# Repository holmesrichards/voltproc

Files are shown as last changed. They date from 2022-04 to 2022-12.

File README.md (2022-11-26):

# Voltage processor

This is a voltage processor module based on designs by ARP and MFOS.

There are two sum sections: One has four inputs, two with attenuators (normaled to -10 V and +10 V) and two with fixed unity gain; the other has two inputs, one with attenuator (normaled to +10 V) and one with fixed unity gain. Each sum has two outputs, normal and inverted.

There also is a lag processor section. Switches allow selection of slow or fast ranges and RC or linear ramping, and a knob adjusts the lag time.

The sum sections are derived from the ARP 2600 schematics. Differences:

* Obviously, this is a module, so there is no normal connection to keyboard CV; instead the second input of the first sum is normaled to +10 V.
* Added second inverting stages for normal plus inverted outputs.
* TL07x op amps in place of LM301.
* Added series output resistors.

The lag processor is based on a section of the MFOS Multi Function Module. Differences:

* Common input and output for both linear and RC circuits.
* Shorter minimum linear lag time.
* 1k series resistors on outputs.

## Current draw
20 mA +12 V, 20 mA -12 V

## Photos

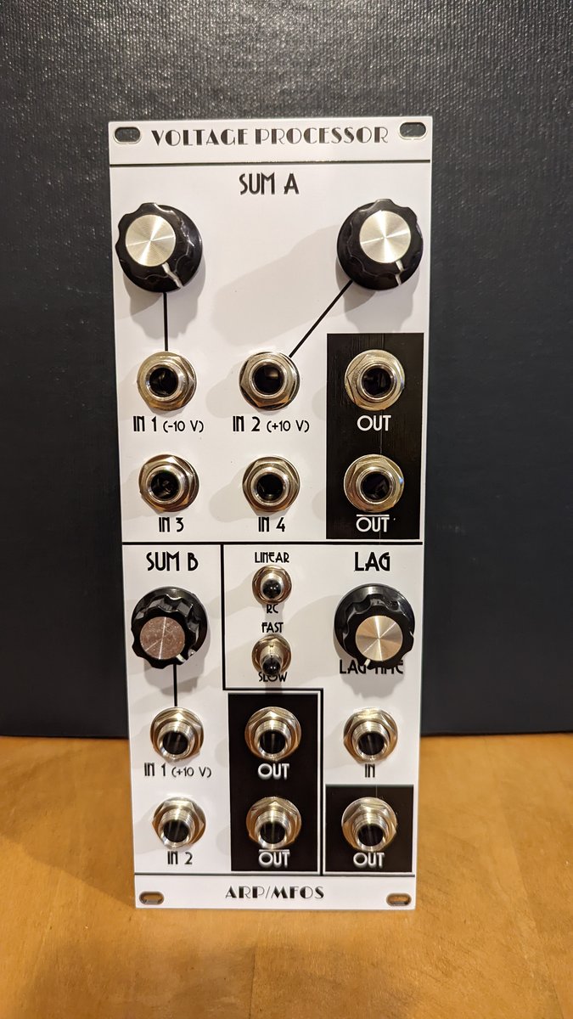
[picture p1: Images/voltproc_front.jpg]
voltproc_front


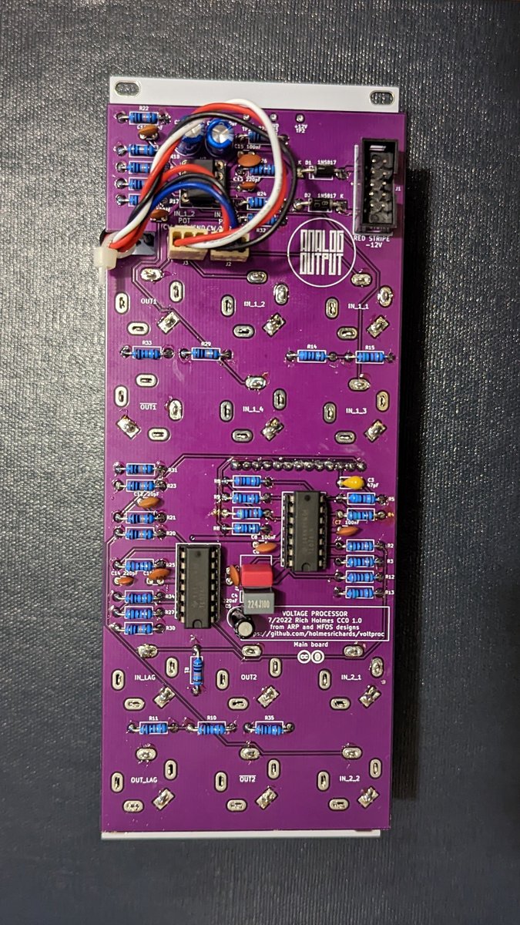
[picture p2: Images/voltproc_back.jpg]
voltproc_front


## Documentation

* [Schematic](Docs/voltproc.pdf)
* PCB layout: [front](Docs/voltproc_layout_front.pdf), [back](Docs/voltproc_layout_back.pdf)
* [BOM](Docs/voltproc_bom.md)
* [Build notes](Docs/build.md)
* [Blog post](https://analogoutputblog.wordpress.com/2022/11/26/processing-voltages/)

## GitHub repository

* [https://github.com/holmesrichards/voltproc](https://github.com/holmesrichards/voltproc)

## Submodules

## Submodules

This repo uses submodules aoKicad and Kosmo_panel, which provide needed libaries for KiCad. To clone:

```
git clone git@github.com:holmesrichards/voltproc.git
git submodule init
git submodule update
```

Alternatively do

```
git clone --recurse-submodules git@github.com:holmesrichards/voltproc.git
```

Or if you download the repository as a zip file, you must also click on the "aoKicad" and "Kosmo\_panel" links on the GitHub page (they'll have "@ something" after them) and download them as separate zip files which you can unzip into this repo's aoKicad and Kosmo\_panel directories.

If desired, copy the files from aoKicad and Kosmo\_panel to wherever you prefer (your KiCad user library directory, for instance, if you have one). Then in KiCad, go into Edit Symbols and add symbol libraries 

```
aoKicad/ao_symbols
Kosmo_panel/Kosmo
```
and go into Edit Footprints and add footprint libraries 
```
aoKicad/ao_tht
Kosmo_panel/Kosmo_panel.
```

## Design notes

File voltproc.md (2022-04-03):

# Voltage processor

This is a utility synth module in Kosmo format. It started as an adaptation of the voltage processor section from the ARP 2600, but with some modifications, and it ended up with the ARP lag processor replaced by one based on that of the Music From Outer Space [Multi Function Module](http://musicfromouterspace.com/analogsynth_new/MULTIFUNCTIONMODULE/MULTIFUNCTIONMODULE.php).

There are three independent sections: Two CV summers and a lag processor.

The summers can be used to add DC offsets to control voltages and to invert them as well as summing them. The first summer has four inputs. Two have attenuators, and these inputs are normalled to -10 V and +10 V. The sum of all four inputs, both inverted and non inverted, goes to output jacks. The second summer is the same but has only two inputs, one with an attenuator and normalled to +10 V.

The lag processor can be used for portamento and glide effects, or as a simple AR envelope generator or a manually controlled low pass filter to smooth rapid changes in a control voltage. The speed is controlled by a knob, and by a switch that selects slow or fast speed ranges. Another switch selects between linear ramping and RC shape lag.

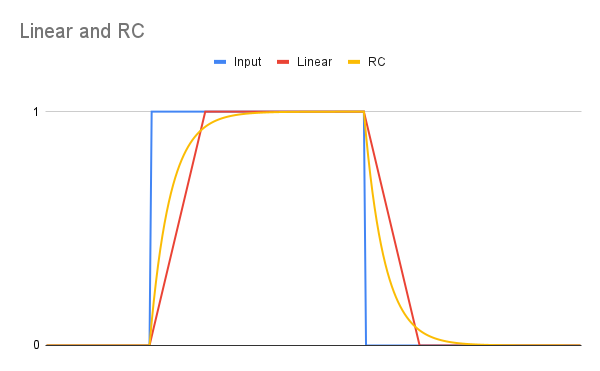
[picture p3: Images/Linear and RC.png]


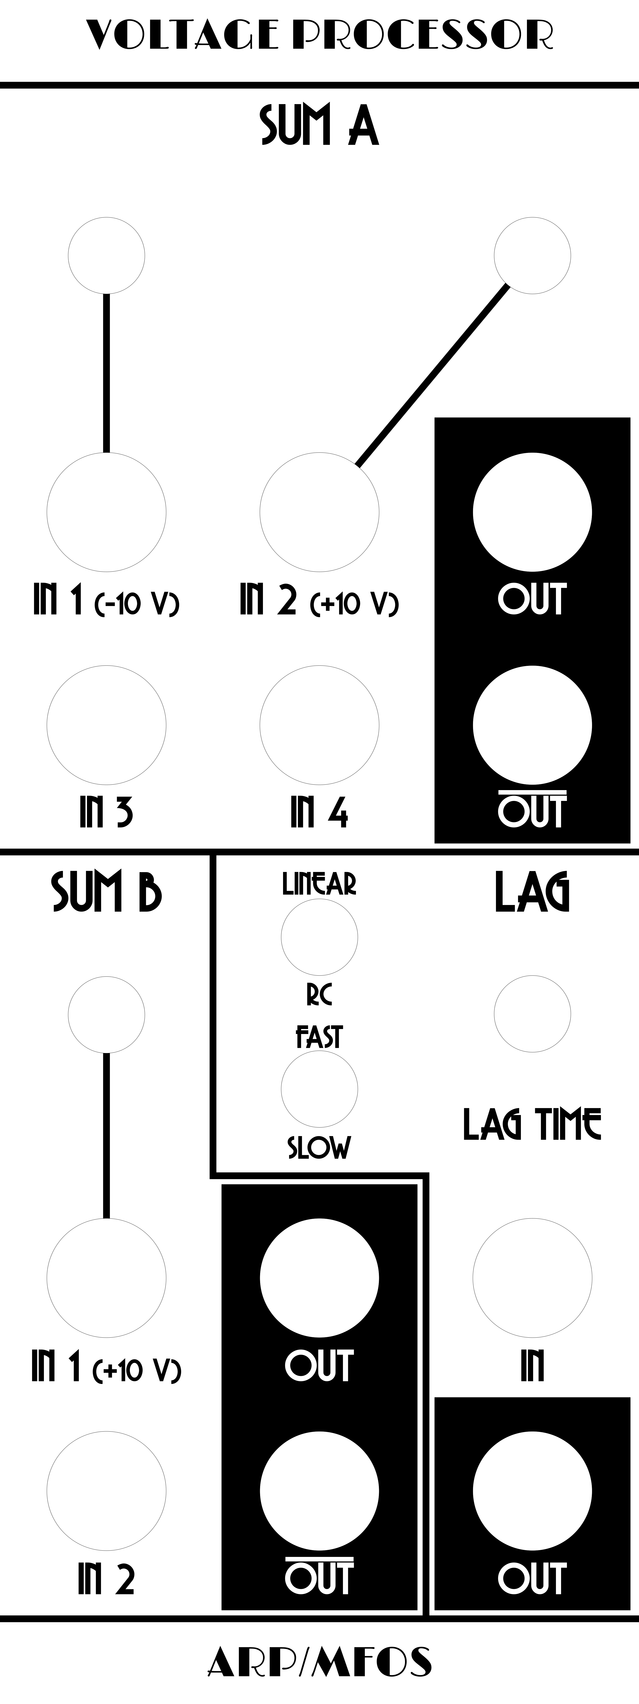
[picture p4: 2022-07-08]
Images/voltproc_panel_art.png

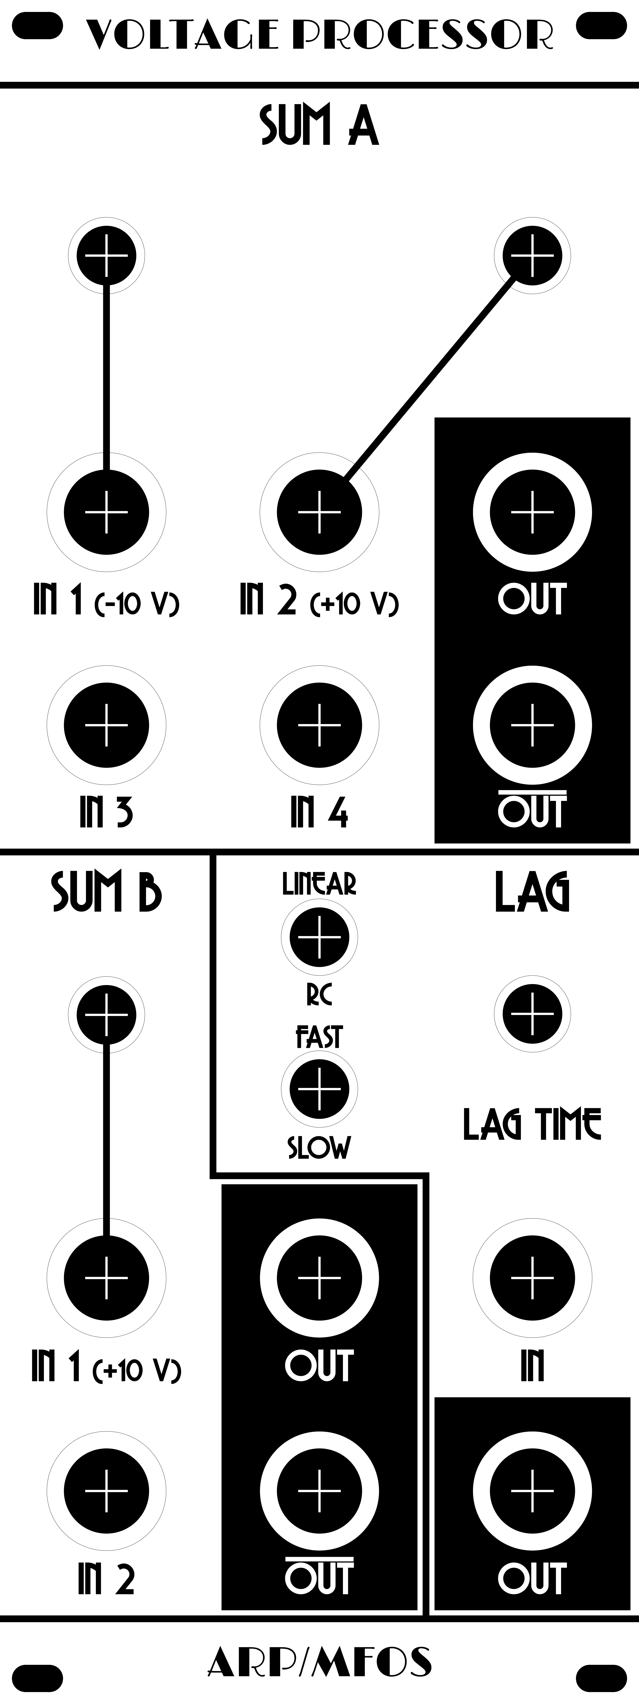
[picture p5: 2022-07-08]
Images/voltproc_panel_holes.png

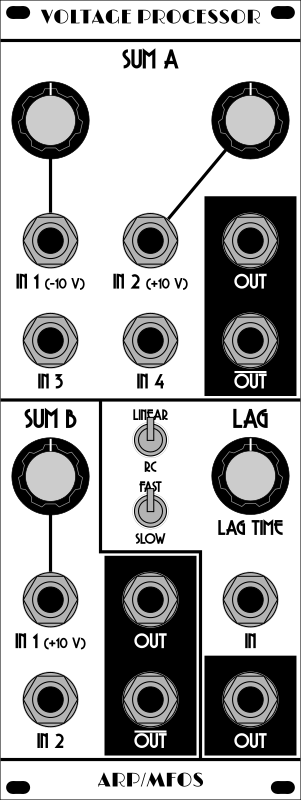
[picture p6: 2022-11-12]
Images/voltproc_panel.png

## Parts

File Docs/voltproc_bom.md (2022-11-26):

# Voltage processor BOM

Sat 26 Nov 2022 12:45:53 PM EST

Generated from schematic by Eeschema 6.0.9-8da3e8f707~117~ubuntu22.04.1

**Component Count:** 81

| Refs | Qty | Component | Description | Vendor | SKU |
| ----- | --- | ---- | --- | ---- | ---- |
| C1, C2 | 2 | 10uF | Electrolytic capacitor, 2.5 mm pitch | Tayda | A-4349 |
| C3 | 1 | 47pF | Ceramic capacitor, 5 mm pitch |  |  |
| C4 | 1 | 220nF | Film capacitor, 5 mm pitch | Tayda | A-984 |
| C5 | 1 | 2.2uF | Non polarized electrolytic capacitor, 2.5 mm pitch | Tayda | A-4223 |
| C6 | 1 | 1uF | Film capacitor, 5 mm pitch | Tayda | A-4755 |
| C7, C8, C9, C10, C15, C16 | 6 | 100nF | Ceramic capacitor, 2.5 mm pitch | Tayda | A-553 |
| C11, C12 | 2 | 20pF | Ceramic capacitor, 2.5 mm pitch |  |  |
| C13, C14 | 2 | 220pF | Ceramic capacitor, 2.5 mm pitch |  |  |
| D1, D2 | 2 | 1N5817 | Schottky Barrier Rectifier Diode, DO-41 | Tayda | A-159 |
| J1 | 1 | Synth_power_2x5 | Shrouded pin header 2.54 mm pitch 2x5 | Tayda | A-2939 |
| J2, J3 | 2 | 3_pin_Molex_header | KK254 Molex header, 3 position | Tayda | A-805 |
| J4 | 1 | Conn_01x13 | Pin header 2.54 mm pitch 1x13 |  |  |
| J5, J6 | 2 | 3_pin_Molex_connector | KK254 Molex connector, 3 position | Tayda | A-827 |
| J7 | 1 | Conn_01x13 | Pin socket 2.54 mm pitch 1x13 |  |  |
| J8, J9, J10, J11, J12, J13, J14, J15, J16, J17, J18, J19 | 12 | Jack | 1/4" audio jack, switched |Tayda  | A-1121 |
| R1, R10, R16, R17, R18, R19, R20, R21, R22, R23, R28, R29, R30, R31 | 14 | 100k | Resistor |  |  |
| R2, R3, R9, R24, R25, R26, R27 | 7 | 10k | Resistor |  |  |
| R4 | 1 | 10M | Resistor |  |  |
| R5 | 1 | 68k | Resistor |  |  |
| R6 | 1 | 20k | Resistor |  |  |
| R7 | 1 | 47k | Resistor |  |  |
| R8 | 1 | 200R | Resistor |  |  |
| R11, R32, R33, R34, R35 | 5 | 1k | Resistor |  |  |
| R12, R14 | 2 | 2.7k | Resistor |  |  |
| R13, R15 | 2 | 15k | Resistor |  |  |
| RV1, RV2 | 2 | B100k | Panel mount potentiometer | Tayda | A-5606 or A-1984 |
| RV3 | 1 | B100k | Board mount vertical 16mm potentiometer | Tayda | A-1628 |
| RV4 | 1 | B1M | Board mount vertical dual gang 16mm potentiometer | Tayda | A-1294 |
| SW1, SW2 | 2 | SW_DPDT_x2 | DPDT miniature toggle switch | Tayda | A-3188 |
| U1, U2 | 2 | TL074 | Quad op amp, DIP-14 | Tayda | A-1138 |
| U3 | 1 | TL072 | Dual op amp, DIP-8 | Tayda | A-037 |
| | 2 | | 14 pin DIP socket | Tayda | A-004 |
| | 1 | | 8 pin DIP socket | Tayda | A-001 |
| | 4 | | knob | | |

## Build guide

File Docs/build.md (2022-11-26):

# Voltage processor build notes

This is a straightforward build. Since there are many panel components be sure to mount the panel on them before soldering them in place. Follow markings on PCB to connect the Molex connectors in correct order to the pots.

**Errata:** In the first run PCB, R7 is marked 4.7k. This is the value used in the MFOS design but I feel it gives too slow a minimum linear ramp. I recommend changing it to 47k. This value has been updated in the design files.

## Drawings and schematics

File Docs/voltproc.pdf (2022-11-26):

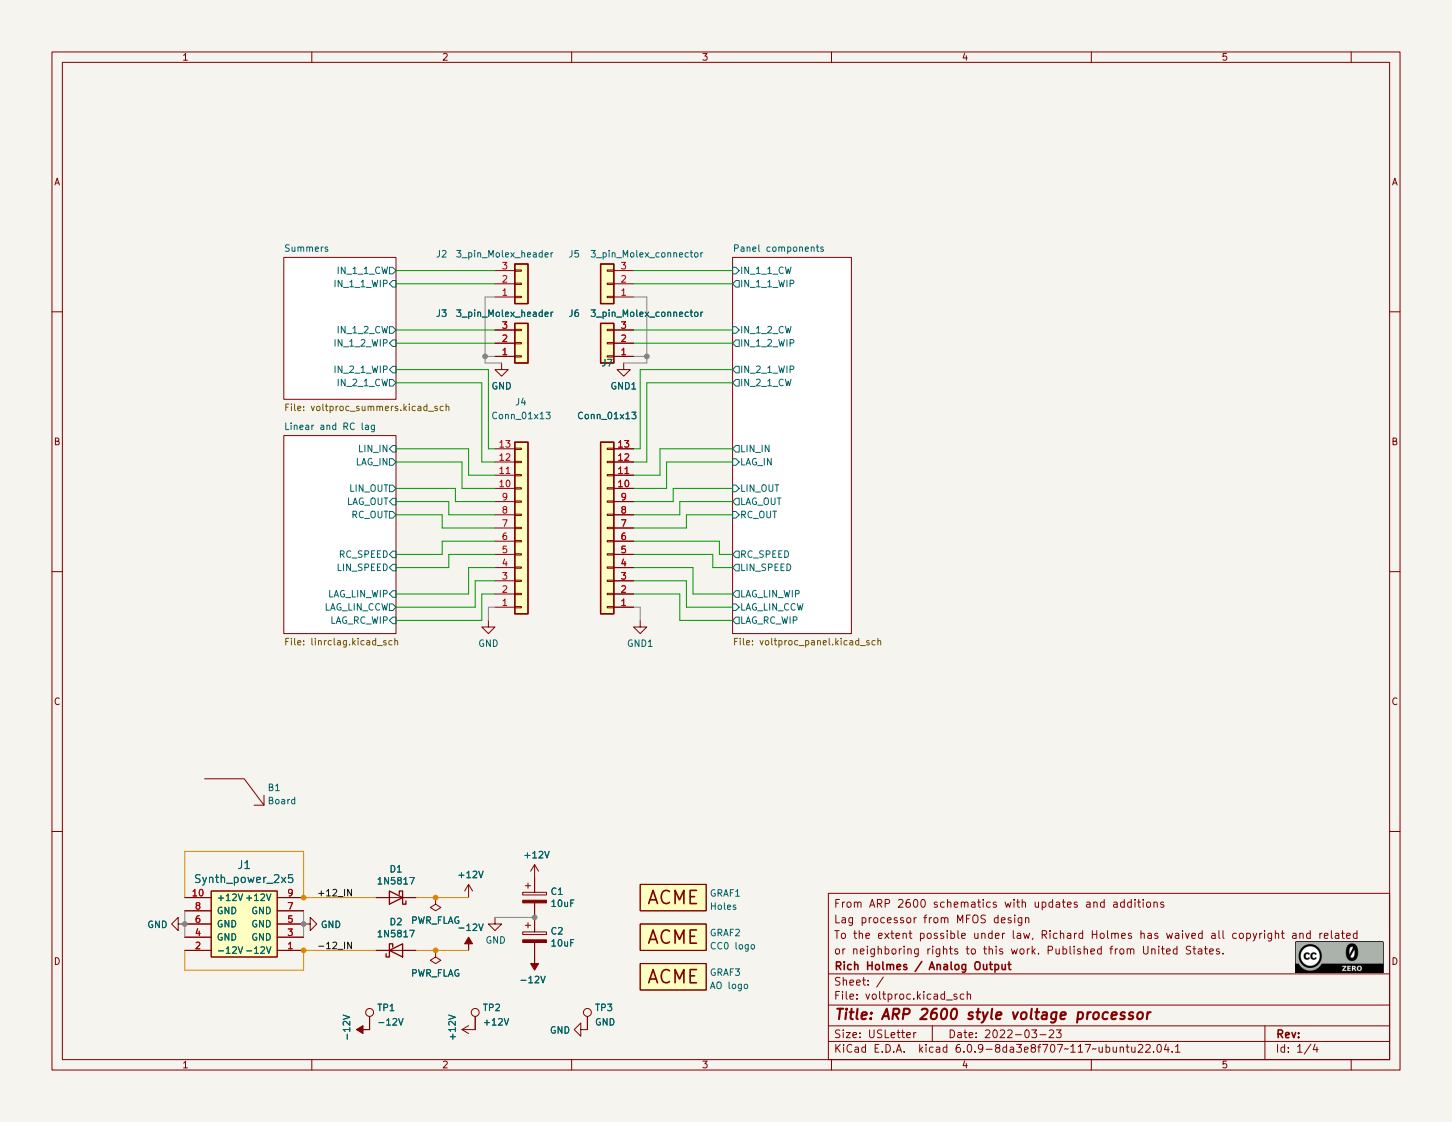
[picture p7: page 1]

Linear and RC lag

From ARP 2600 schematics with updates and additions
Lag processor from MFOS design
To the extent possible under law, Richard Holmes has waived all copyright and related
or neighboring rights to this work. Published from United States.
File: voltproc.kicad_sch Sheet: / Rich Holmes / Analog Output

Id: 1/4 Title: ARP 2600 style voltage processor

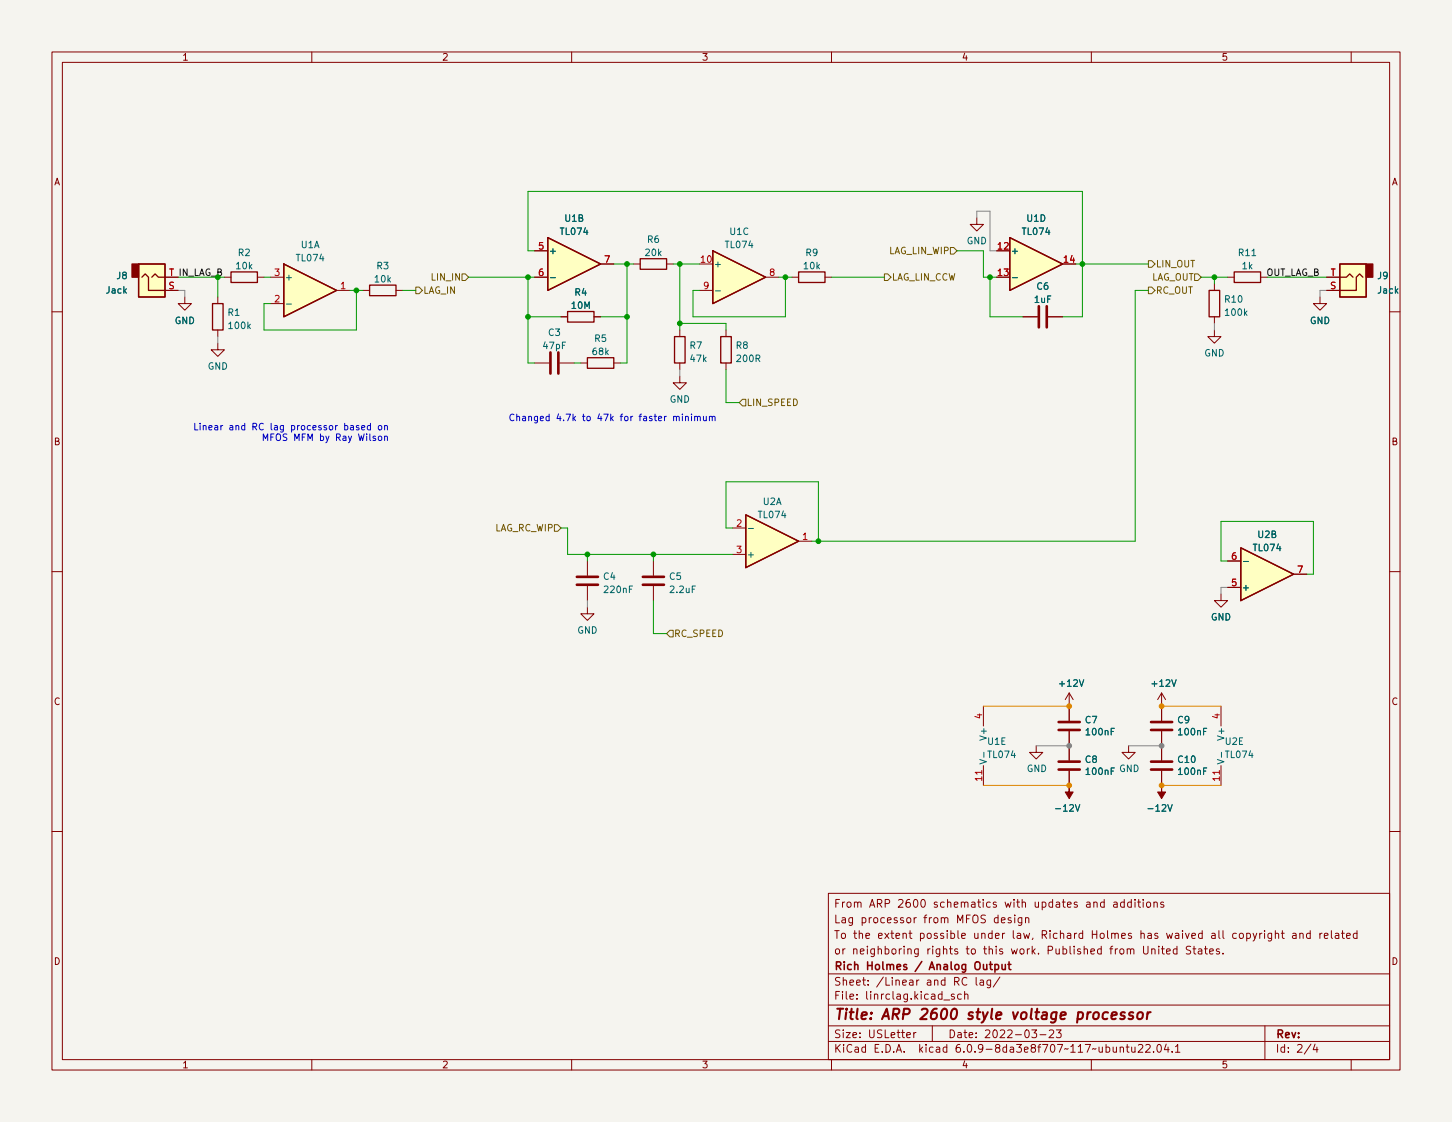
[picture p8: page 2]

Linear and RC lag processor based on

From ARP 2600 schematics with updates and additions
Lag processor from MFOS design
To the extent possible under law, Richard Holmes has waived all copyright and related
or neighboring rights to this work. Published from United States.
Rich Holmes / Analog Output
Sheet: /Linear and RC lag/
File: linrclag.kicad_sch
Id: 2/4 Title: ARP 2600 style voltage processor

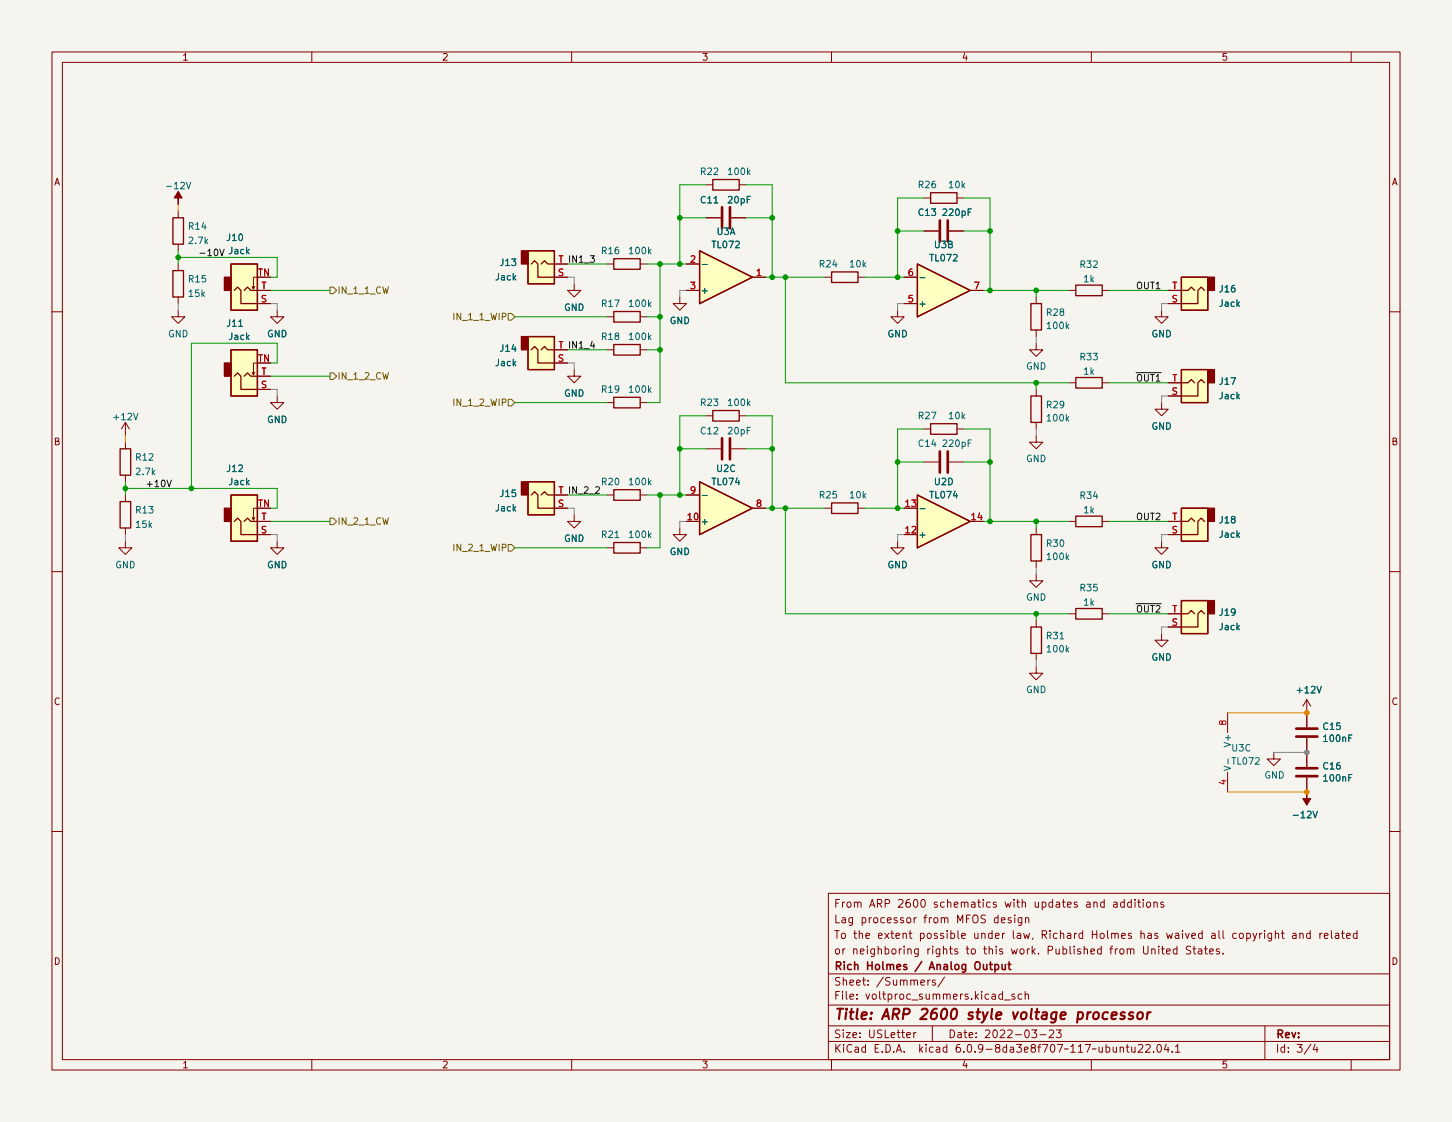
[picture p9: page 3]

From ARP 2600 schematics with updates and additions
Lag processor from MFOS design
To the extent possible under law, Richard Holmes has waived all copyright and related
or neighboring rights to this work. Published from United States.
File: voltproc_summers.kicad_sch Sheet: /Summers/ Rich Holmes / Analog Output

Id: 3/4 Title: ARP 2600 style voltage processor

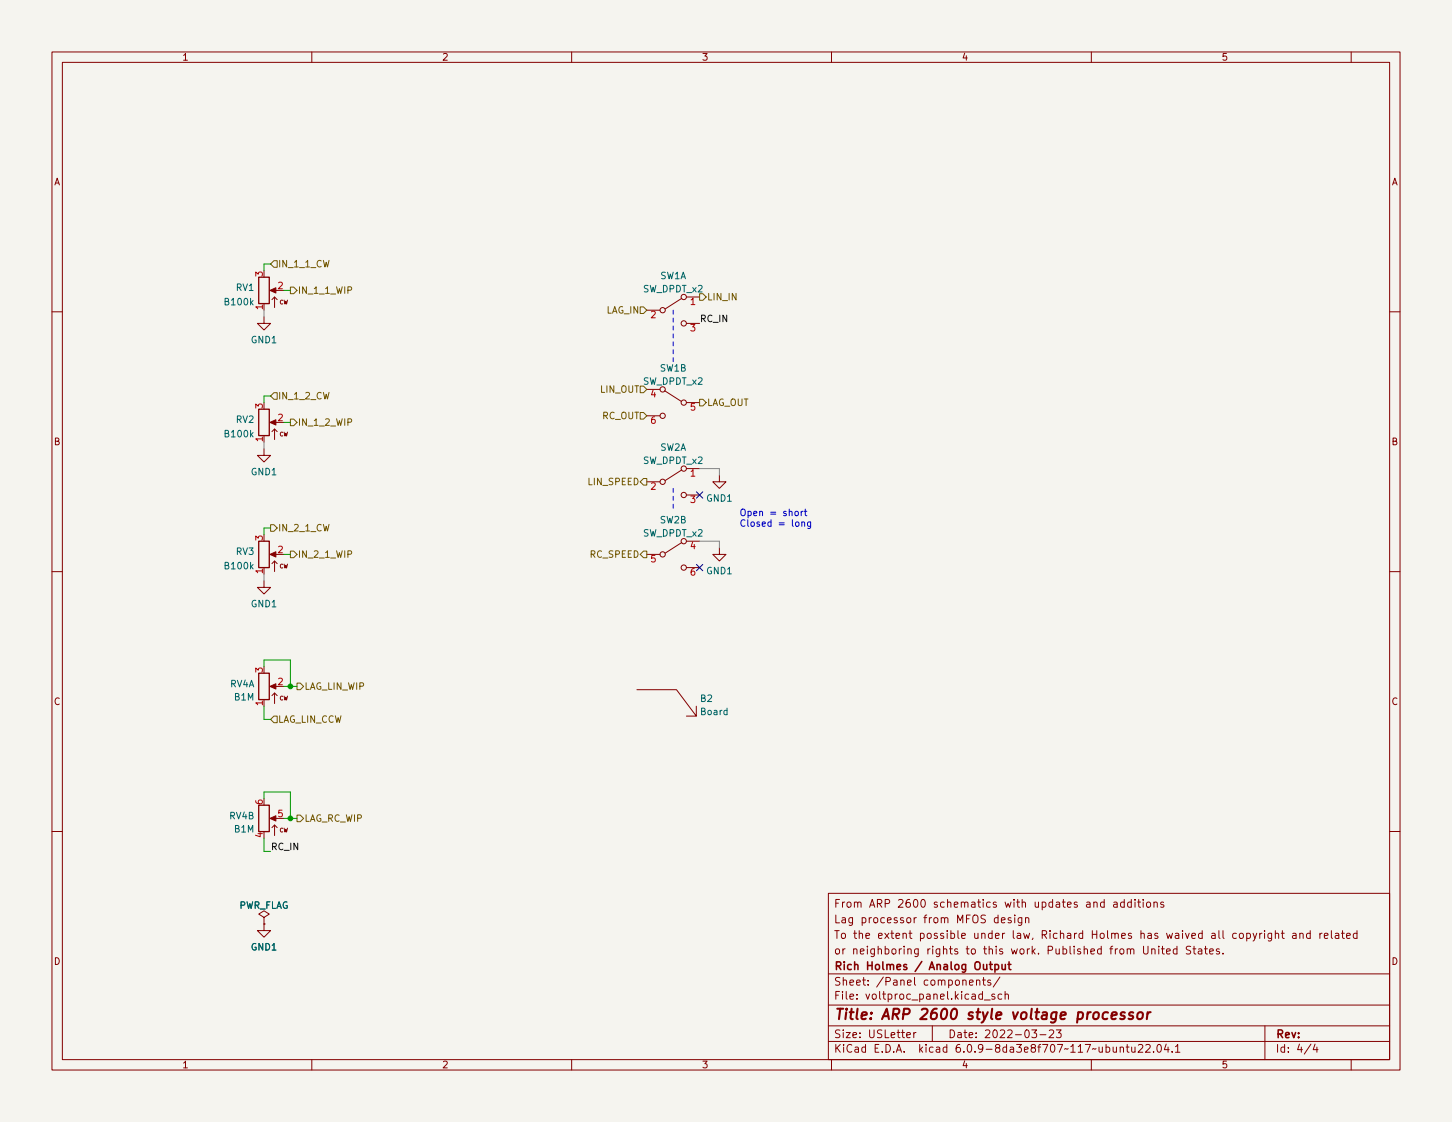
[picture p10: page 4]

From ARP 2600 schematics with updates and additions
Lag processor from MFOS design
To the extent possible under law, Richard Holmes has waived all copyright and related
or neighboring rights to this work. Published from United States.
Rich Holmes / Analog Output
Sheet: /Panel components/
File: voltproc_panel.kicad_sch
Id: 4/4 Title: ARP 2600 style voltage processor

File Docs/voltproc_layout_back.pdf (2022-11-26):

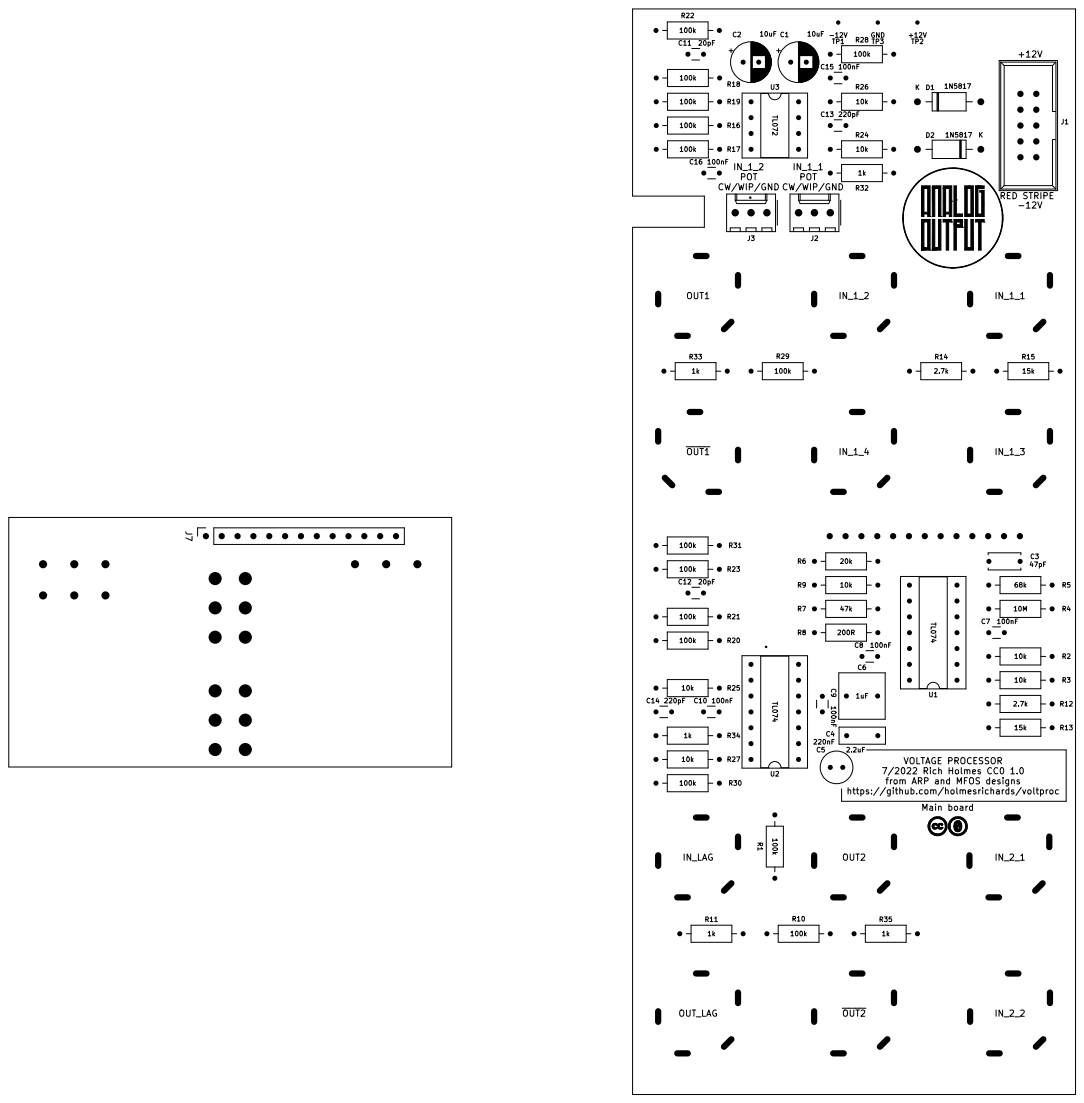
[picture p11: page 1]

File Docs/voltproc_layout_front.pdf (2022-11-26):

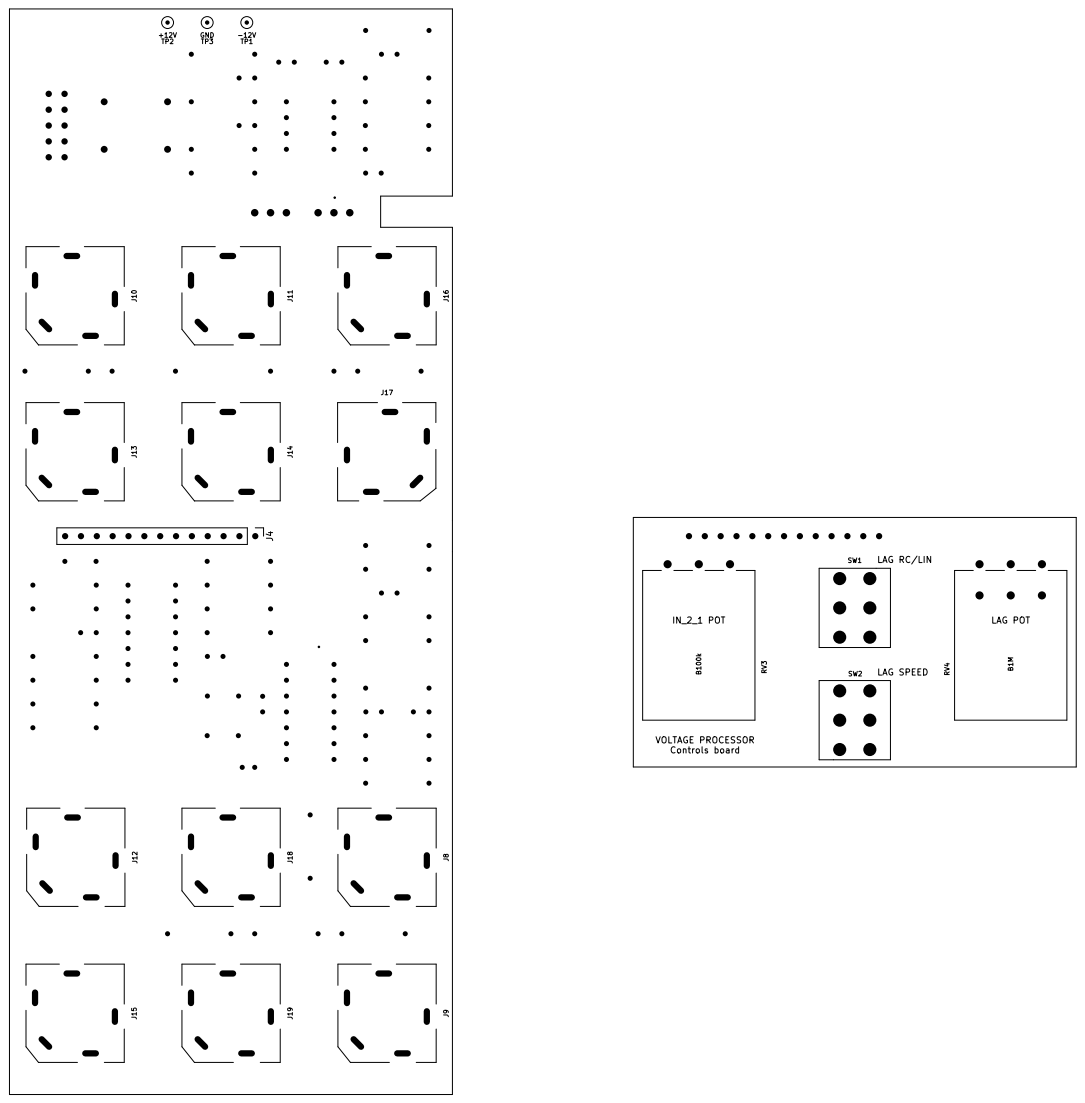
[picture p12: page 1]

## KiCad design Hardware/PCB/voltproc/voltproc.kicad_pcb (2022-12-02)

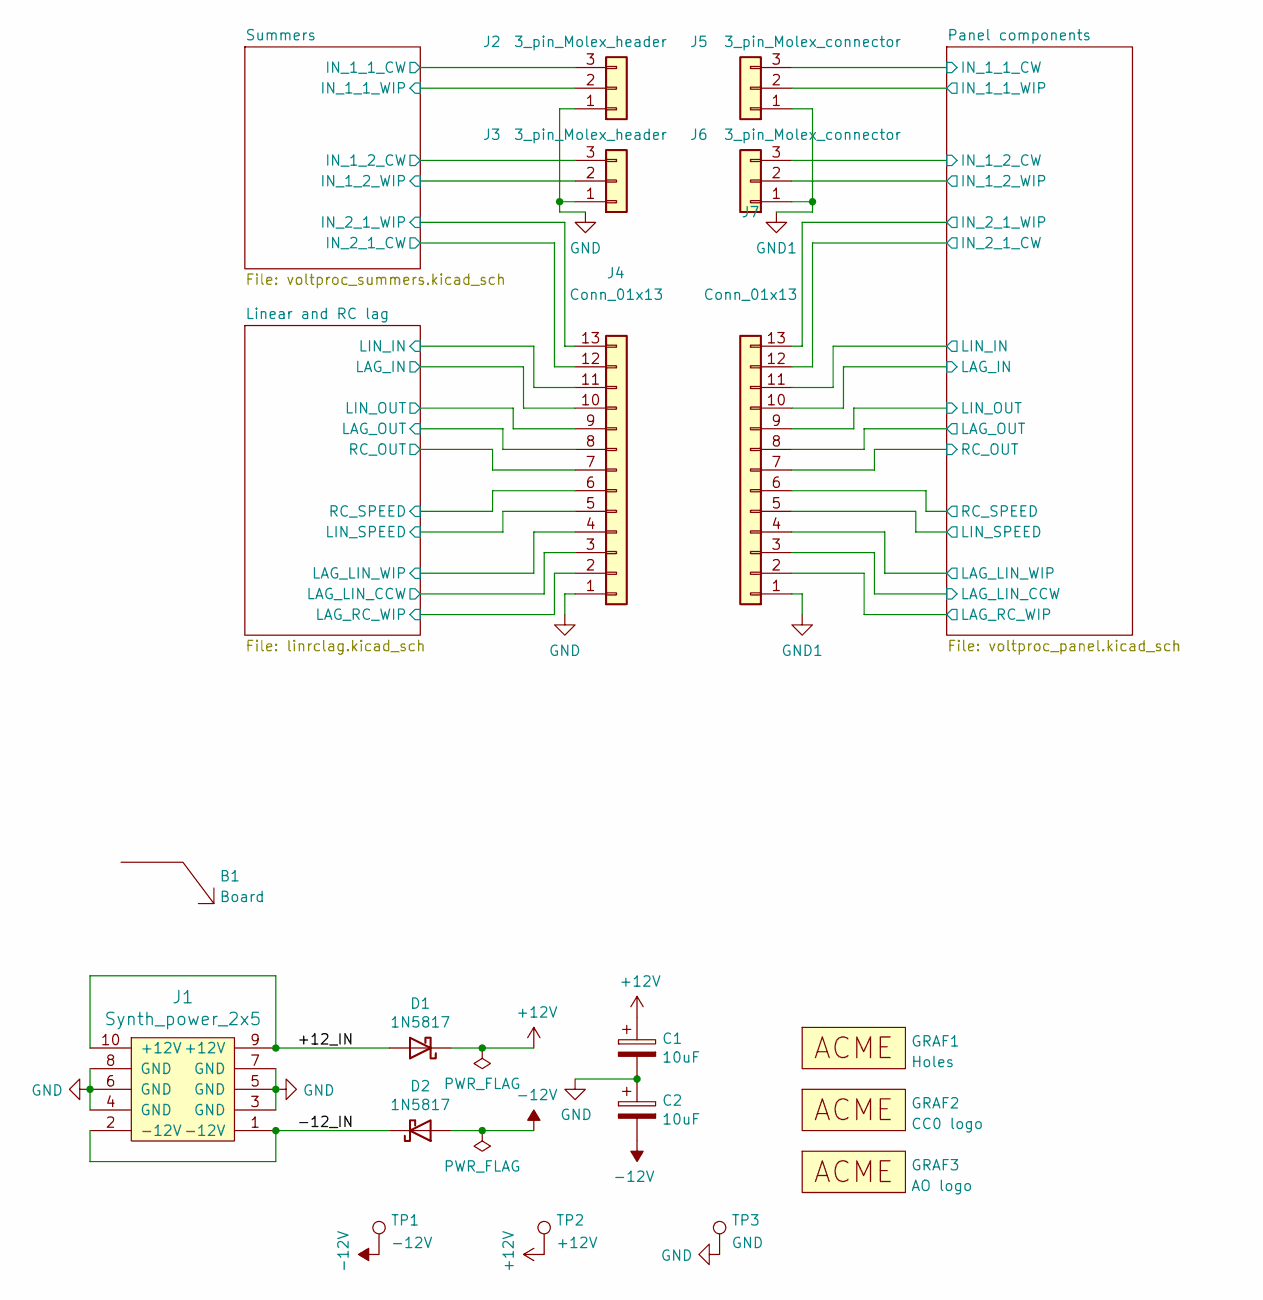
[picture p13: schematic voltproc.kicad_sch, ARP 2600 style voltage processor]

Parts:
B1: Board; Board_Marker
C1, C2: 10uF; CP_Radial_D6.3mm_P2.50mm
D1, D2: 1N5817; D_DO-41_SOD81_P10.16mm_Horizontal
GRAF1: Holes; voltproc_panel_holes
GRAF2: CC0 logo; CC0_logo
GRAF3: AO logo; analogoutput
J1: Synth_power_2x5; Power_Header
J2, J3: 3_pin_Molex_header; Molex_KK-254_AE-6410-03A_1x03_P2.54mm_Vertical
J4: Conn_01x13; PinHeader_1x13_P2.54mm_Vertical
J5, J6: 3_pin_Molex_connector; Molex_KK-254_AE-6410-03A_1x03_P2.54mm_Vertical
J7: Conn_01x13; PinSocket_1x13_P2.54mm_Vertical
TP1: -12V; TestPoint_THTPad_D1.5mm_Drill0.7mm
TP2: +12V; TestPoint_THTPad_D1.5mm_Drill0.7mm
TP3: GND; TestPoint_THTPad_D1.5mm_Drill0.7mm

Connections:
+12V: C1.1, D1.1 (K), TP2.1; also elsewhere on the board
-12V: C2.2, D2.2 (A), TP1.1; also elsewhere on the board
/+12_IN: D1.2 (A), J1.9 (+12V), J1.10 (+12V)
/-12_IN: D2.1 (K), J1.1 (-12V), J1.2 (-12V)
/Linear and RC lag/LAG_IN: J4.10; also elsewhere on the board
/Linear and RC lag/LAG_LIN_CCW: J4.3; also elsewhere on the board
/Linear and RC lag/LAG_LIN_WIP: J4.4; also elsewhere on the board
/Linear and RC lag/LAG_OUT: J4.8; also elsewhere on the board
/Linear and RC lag/LAG_RC_WIP: J4.2; also elsewhere on the board
/Linear and RC lag/LIN_IN: J4.11; also elsewhere on the board
/Linear and RC lag/LIN_OUT: J4.9; also elsewhere on the board
/Linear and RC lag/LIN_SPEED: J4.5; also elsewhere on the board
/Linear and RC lag/RC_OUT: J4.7; also elsewhere on the board
/Linear and RC lag/RC_SPEED: J4.6; also elsewhere on the board
/Panel components/IN_2_1_CW: J7.12; also elsewhere on the board
/Panel components/IN_2_1_WIP: J7.13; also elsewhere on the board
/Panel components/LAG_IN: J7.10; also elsewhere on the board
/Panel components/LAG_LIN_CCW: J7.3; also elsewhere on the board
/Panel components/LAG_LIN_WIP: J7.4; also elsewhere on the board
/Panel components/LAG_OUT: J7.8; also elsewhere on the board
/Panel components/LAG_RC_WIP: J7.2; also elsewhere on the board
/Panel components/LIN_IN: J7.11; also elsewhere on the board
/Panel components/LIN_OUT: J7.9; also elsewhere on the board
/Panel components/LIN_SPEED: J7.5; also elsewhere on the board
/Panel components/RC_OUT: J7.7; also elsewhere on the board
/Panel components/RC_SPEED: J7.6; also elsewhere on the board
/Summers/IN_1_1_CW: J2.3; also elsewhere on the board
/Summers/IN_1_1_WIP: J2.2; also elsewhere on the board
/Summers/IN_1_2_CW: J3.3; also elsewhere on the board
/Summers/IN_1_2_WIP: J3.2; also elsewhere on the board
/Summers/IN_2_1_CW: J4.12; also elsewhere on the board
/Summers/IN_2_1_WIP: J4.13; also elsewhere on the board
GND: C1.2, C2.1, J1.3 (GND), J1.4 (GND), J1.5 (GND), J1.6 (GND), J1.7 (GND), J1.8 (GND), J2.1, J3.1, J4.1, TP3.1; also elsewhere on the board
GND1: J5.1, J6.1, J7.1; also elsewhere on the board

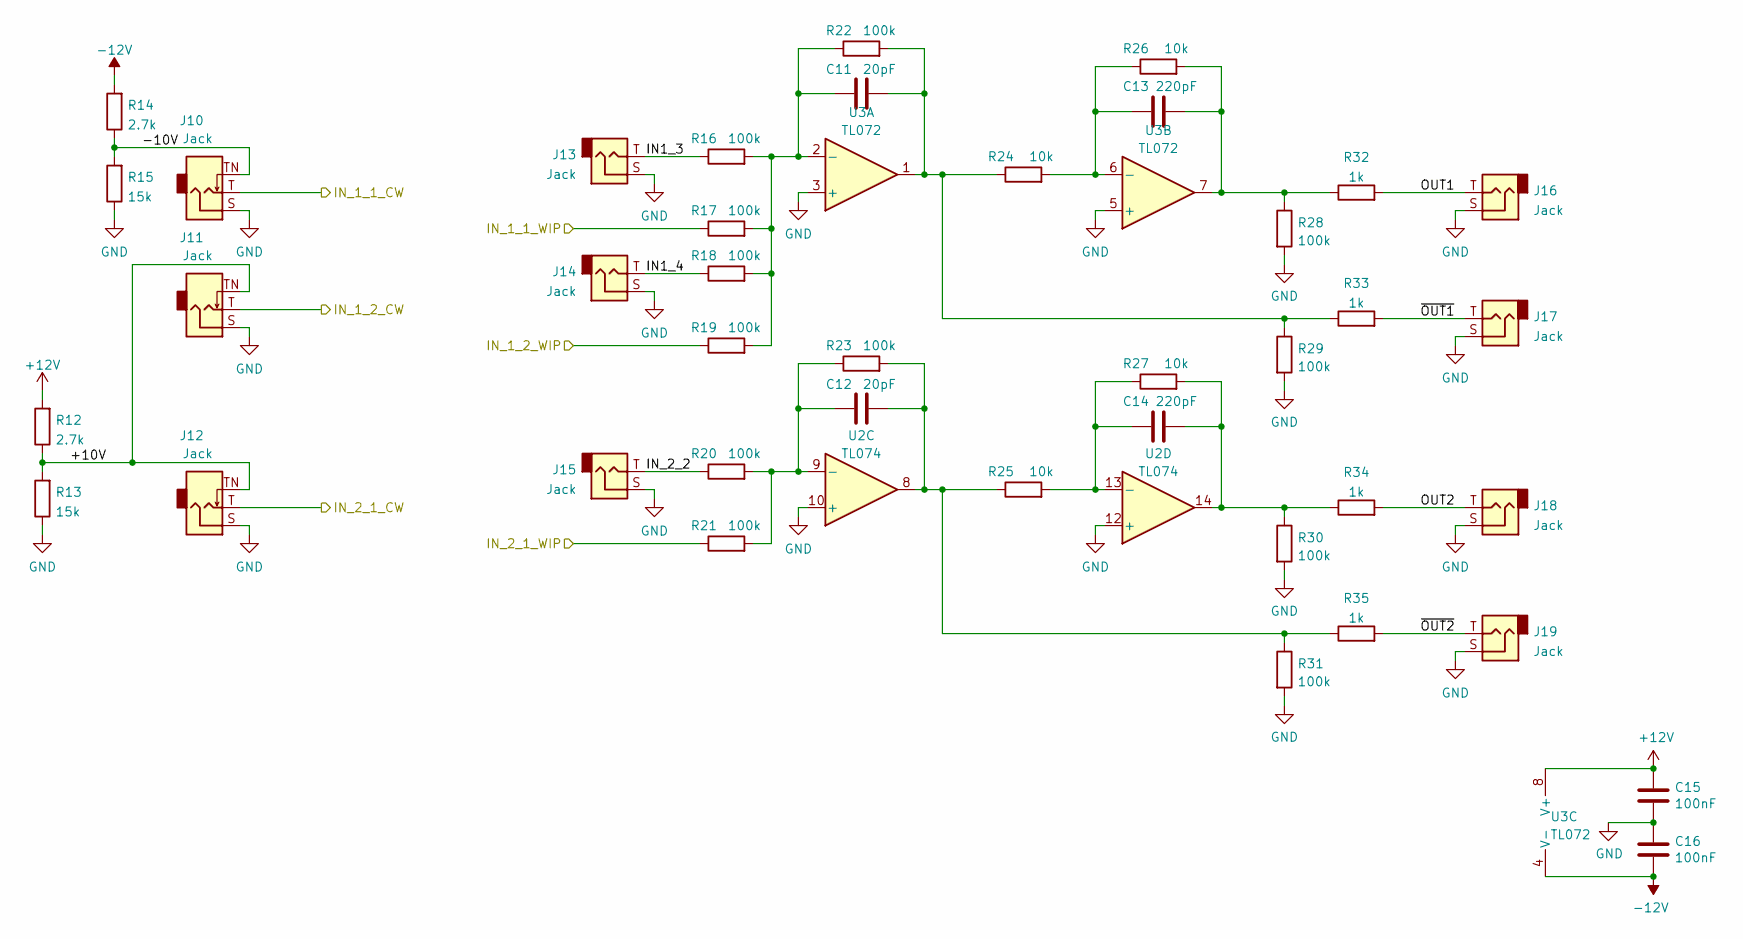
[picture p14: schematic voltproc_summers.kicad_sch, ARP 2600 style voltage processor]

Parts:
C11, C12: 20pF; C_Disc_D3.0mm_W1.6mm_P2.50mm
C13, C14: 220pF; C_Disc_D3.0mm_W1.6mm_P2.50mm
C15, C16: 100nF; C_Disc_D3.0mm_W1.6mm_P2.50mm
J10, J11, J12, J13, J14, J15, J16, J17, J18, J19: Jack; Jack_6.35mm_PJ_629HAN_slots
R12, R14: 2.7k; R_Axial_DIN0207_L6.3mm_D2.5mm_P10.16mm_Horizontal
R13, R15: 15k; R_Axial_DIN0207_L6.3mm_D2.5mm_P10.16mm_Horizontal
R16, R17, R18, R19, R20, R21, R22, R23, R28, R29, R30, R31: 100k; R_Axial_DIN0207_L6.3mm_D2.5mm_P10.16mm_Horizontal
R24, R25, R26, R27: 10k; R_Axial_DIN0207_L6.3mm_D2.5mm_P10.16mm_Horizontal
R32, R33, R34, R35: 1k; R_Axial_DIN0207_L6.3mm_D2.5mm_P10.16mm_Horizontal
U2: TL074; DIP-14_W7.62mm_Socket_LongPads
U3: TL072; DIP-8_W7.62mm_Socket_LongPads

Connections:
+12V: C15.1, R12.2, U3.8 (V+); also elsewhere on the board
-12V: C16.2, R14.2, U3.4 (V-); also elsewhere on the board
/Summers/+10V: J11.TN, J12.TN, R12.1, R13.2
/Summers/-10V: J10.TN, R14.1, R15.2
/Summers/IN1_3: J13.T, R16.1
/Summers/IN1_4: J14.T, R18.1
/Summers/IN_1_1_CW: J10.T; also elsewhere on the board
/Summers/IN_1_1_WIP: R17.1; also elsewhere on the board
/Summers/IN_1_2_CW: J11.T; also elsewhere on the board
/Summers/IN_1_2_WIP: R19.1; also elsewhere on the board
/Summers/IN_2_1_CW: J12.T; also elsewhere on the board
/Summers/IN_2_1_WIP: R21.1; also elsewhere on the board
/Summers/IN_2_2: J15.T, R20.1
/Summers/OUT1: J16.T, R32.2
/Summers/OUT2: J18.T, R34.2
/Summers/~OUT1: J17.T, R33.2
/Summers/~OUT2: J19.T, R35.2
GND: C15.2, C16.1, J10.S, J11.S, J12.S, J13.S, J14.S, J15.S, J16.S, J17.S, J18.S, J19.S, R13.1, R15.1, R28.2, R29.2, R30.2, R31.2, U2.10 (+), U2.12 (+), U3.3 (+), U3.5 (+); also elsewhere on the board
unnamed: C11.1, R16.2, R17.2, R18.2, R19.2, R22.1, U3.2 (-)
unnamed: C11.2, R22.2, R24.1, R29.1, R33.1, U3.1
unnamed: C12.1, R20.2, R21.2, R23.1, U2.9 (-)
unnamed: C12.2, R23.2, R25.1, R31.1, R35.1, U2.8
unnamed: C13.1, R24.2, R26.1, U3.6 (-)
unnamed: C13.2, R26.2, R28.1, R32.1, U3.7
unnamed: C14.1, R25.2, R27.1, U2.13 (-)
unnamed: C14.2, R27.2, R30.1, R34.1, U2.14

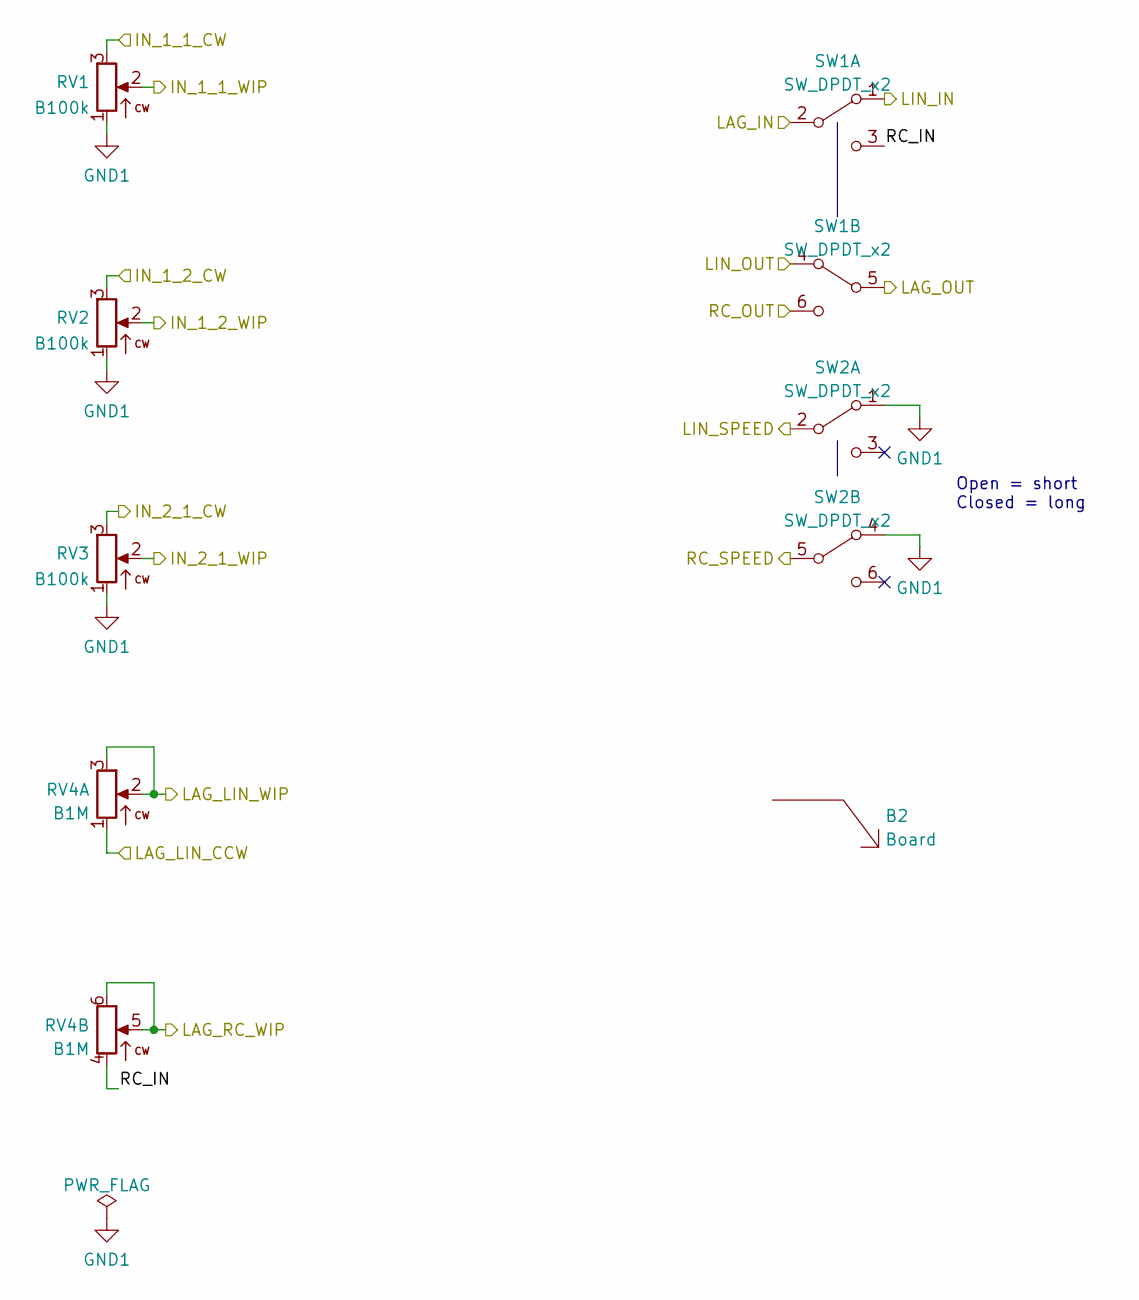
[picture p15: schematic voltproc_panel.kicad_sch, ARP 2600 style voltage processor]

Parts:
B2: Board; Board_Marker
RV1, RV2: B100k
RV3: B100k; Potentiometer_Alpha_16mm_Single_Vertical
RV4: B1M; Potentiometer_Alpha_16mm_Dual_Vertical
SW1, SW2: SW_DPDT_x2; DPDT-toggle-switch-1M-seriesx

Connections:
/Panel components/IN_2_1_CW: RV3.3; also elsewhere on the board
/Panel components/IN_2_1_WIP: RV3.2; also elsewhere on the board
/Panel components/LAG_IN: SW1.2 (B); also elsewhere on the board
/Panel components/LAG_LIN_CCW: RV4.1; also elsewhere on the board
/Panel components/LAG_LIN_WIP: RV4.2, RV4.3; also elsewhere on the board
/Panel components/LAG_OUT: SW1.5 (B); also elsewhere on the board
/Panel components/LAG_RC_WIP: RV4.5, RV4.6; also elsewhere on the board
/Panel components/LIN_IN: SW1.1 (A); also elsewhere on the board
/Panel components/LIN_OUT: SW1.4 (A); also elsewhere on the board
/Panel components/LIN_SPEED: SW2.2 (B); also elsewhere on the board
/Panel components/RC_IN: RV4.4, SW1.3 (C)
/Panel components/RC_OUT: SW1.6 (C); also elsewhere on the board
/Panel components/RC_SPEED: SW2.5 (B); also elsewhere on the board
GND1: RV1.1, RV2.1, RV3.1, SW2.1 (A), SW2.4 (A); also elsewhere on the board

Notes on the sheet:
Open = short Closed = long

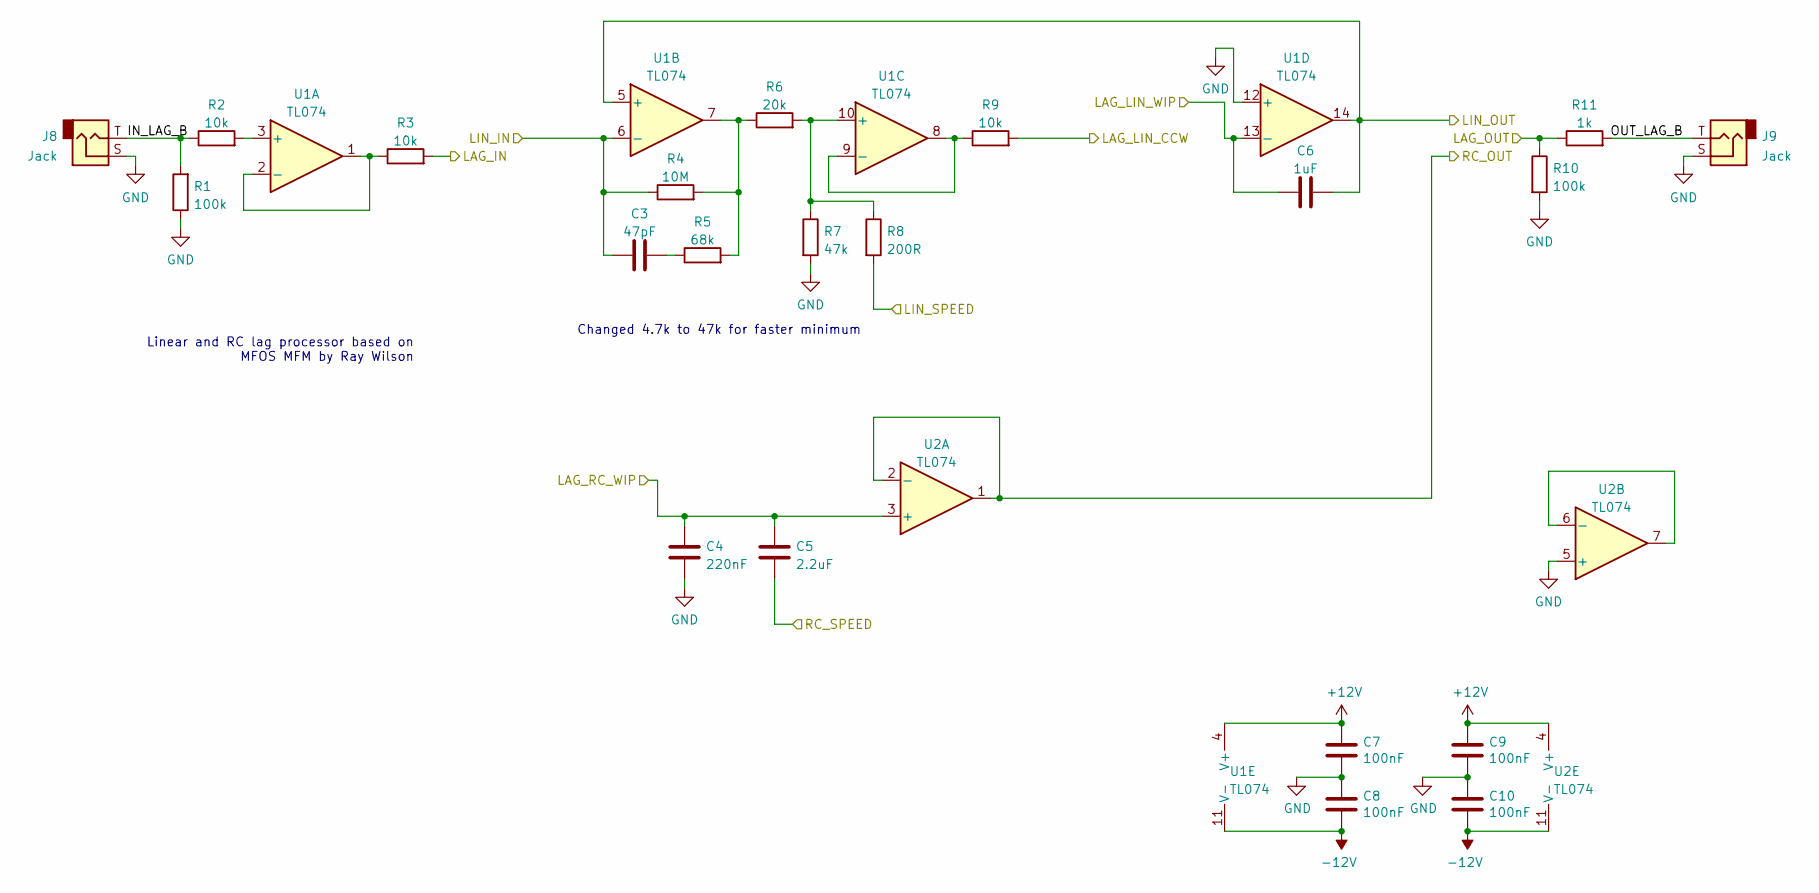
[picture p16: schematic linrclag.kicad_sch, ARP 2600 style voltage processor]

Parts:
C3: 47pF; C_Disc_D5.0mm_W2.5mm_P5.00mm
C4: 220nF; C_Rect_L7.2mm_W2.5mm_P5.00mm_FKS2_FKP2_MKS2_MKP2
C5: 2.2uF; C_Radial_D5.0mm_H11.0mm_P2.00mm
C6: 1uF; C_Rect_L7.2mm_W7.2mm_P5.00mm_FKS2_FKP2_MKS2_MKP2
C7, C8, C9, C10: 100nF; C_Disc_D3.0mm_W1.6mm_P2.50mm
J8, J9: Jack; Jack_6.35mm_PJ_629HAN_slots
R1, R10: 100k; R_Axial_DIN0207_L6.3mm_D2.5mm_P10.16mm_Horizontal
R2, R3, R9: 10k; R_Axial_DIN0207_L6.3mm_D2.5mm_P10.16mm_Horizontal
R4: 10M; R_Axial_DIN0207_L6.3mm_D2.5mm_P10.16mm_Horizontal
R5: 68k; R_Axial_DIN0207_L6.3mm_D2.5mm_P10.16mm_Horizontal
R6: 20k; R_Axial_DIN0207_L6.3mm_D2.5mm_P10.16mm_Horizontal
R7: 47k; R_Axial_DIN0207_L6.3mm_D2.5mm_P10.16mm_Horizontal
R8: 200R; R_Axial_DIN0207_L6.3mm_D2.5mm_P10.16mm_Horizontal
R11: 1k; R_Axial_DIN0207_L6.3mm_D2.5mm_P10.16mm_Horizontal
U1, U2: TL074; DIP-14_W7.62mm_Socket_LongPads

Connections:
+12V: C7.1, C9.1, U1.4 (V+), U2.4 (V+); also elsewhere on the board
-12V: C8.2, C10.2, U1.11 (V-), U2.11 (V-); also elsewhere on the board
/Linear and RC lag/IN_LAG_B: J8.T, R1.2, R2.1
/Linear and RC lag/LAG_IN: R3.2; also elsewhere on the board
/Linear and RC lag/LAG_LIN_CCW: R9.2; also elsewhere on the board
/Linear and RC lag/LAG_LIN_WIP: C6.1, U1.13 (-); also elsewhere on the board
/Linear and RC lag/LAG_OUT: R10.1, R11.1; also elsewhere on the board
/Linear and RC lag/LAG_RC_WIP: C4.1, C5.1, U2.3 (+); also elsewhere on the board
/Linear and RC lag/LIN_IN: C3.1, R4.1, U1.6 (-); also elsewhere on the board
/Linear and RC lag/LIN_OUT: C6.2, U1.5 (+), U1.14; also elsewhere on the board
/Linear and RC lag/LIN_SPEED: R8.2; also elsewhere on the board
/Linear and RC lag/OUT_LAG_B: J9.T, R11.2
/Linear and RC lag/RC_OUT: U2.1, U2.2 (-); also elsewhere on the board
/Linear and RC lag/RC_SPEED: C5.2; also elsewhere on the board
GND: C4.2, C7.2, C8.1, C9.2, C10.1, J8.S, J9.S, R1.1, R7.2, R10.2, U1.12 (+), U2.5 (+); also elsewhere on the board
unnamed: C3.2, R5.1
unnamed: R2.2, U1.3 (+)
unnamed: R3.1, U1.1, U1.2 (-)
unnamed: R4.2, R5.2, R6.1, U1.7
unnamed: R6.2, R7.1, R8.1, U1.10 (+)
unnamed: R9.1, U1.8, U1.9 (-)
unnamed: U2.6 (-), U2.7

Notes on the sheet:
Linear and RC lag processor based on MFOS MFM by Ray Wilson
Changed 4.7k to 47k for faster minimum

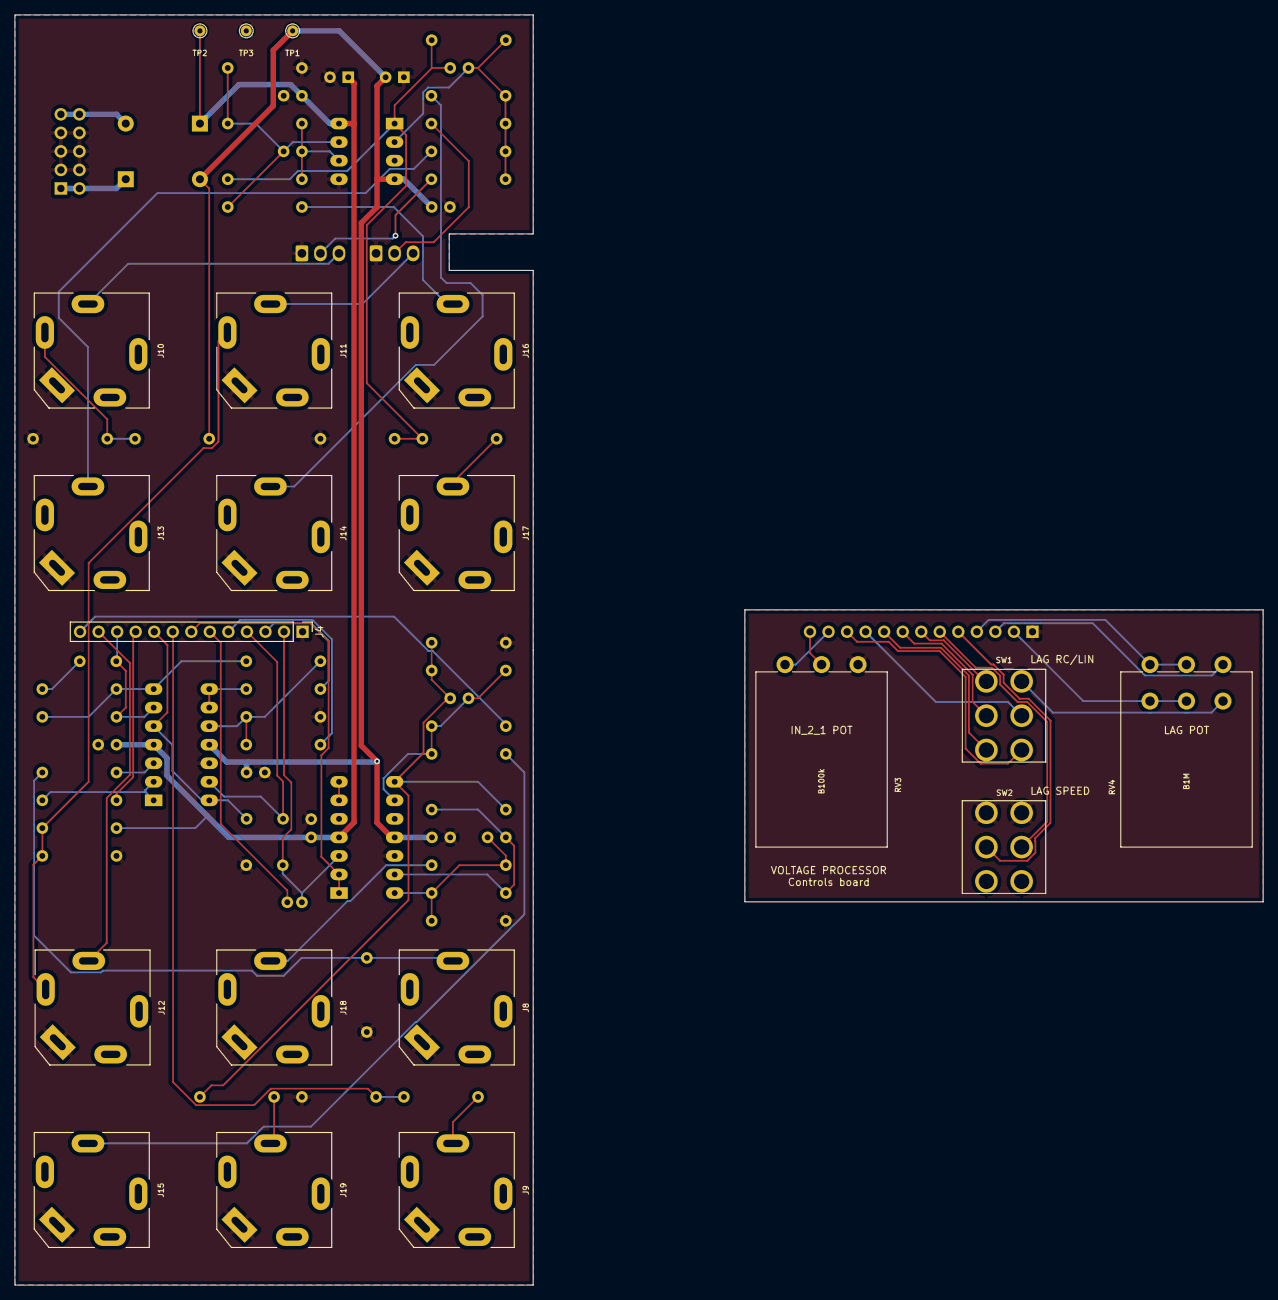
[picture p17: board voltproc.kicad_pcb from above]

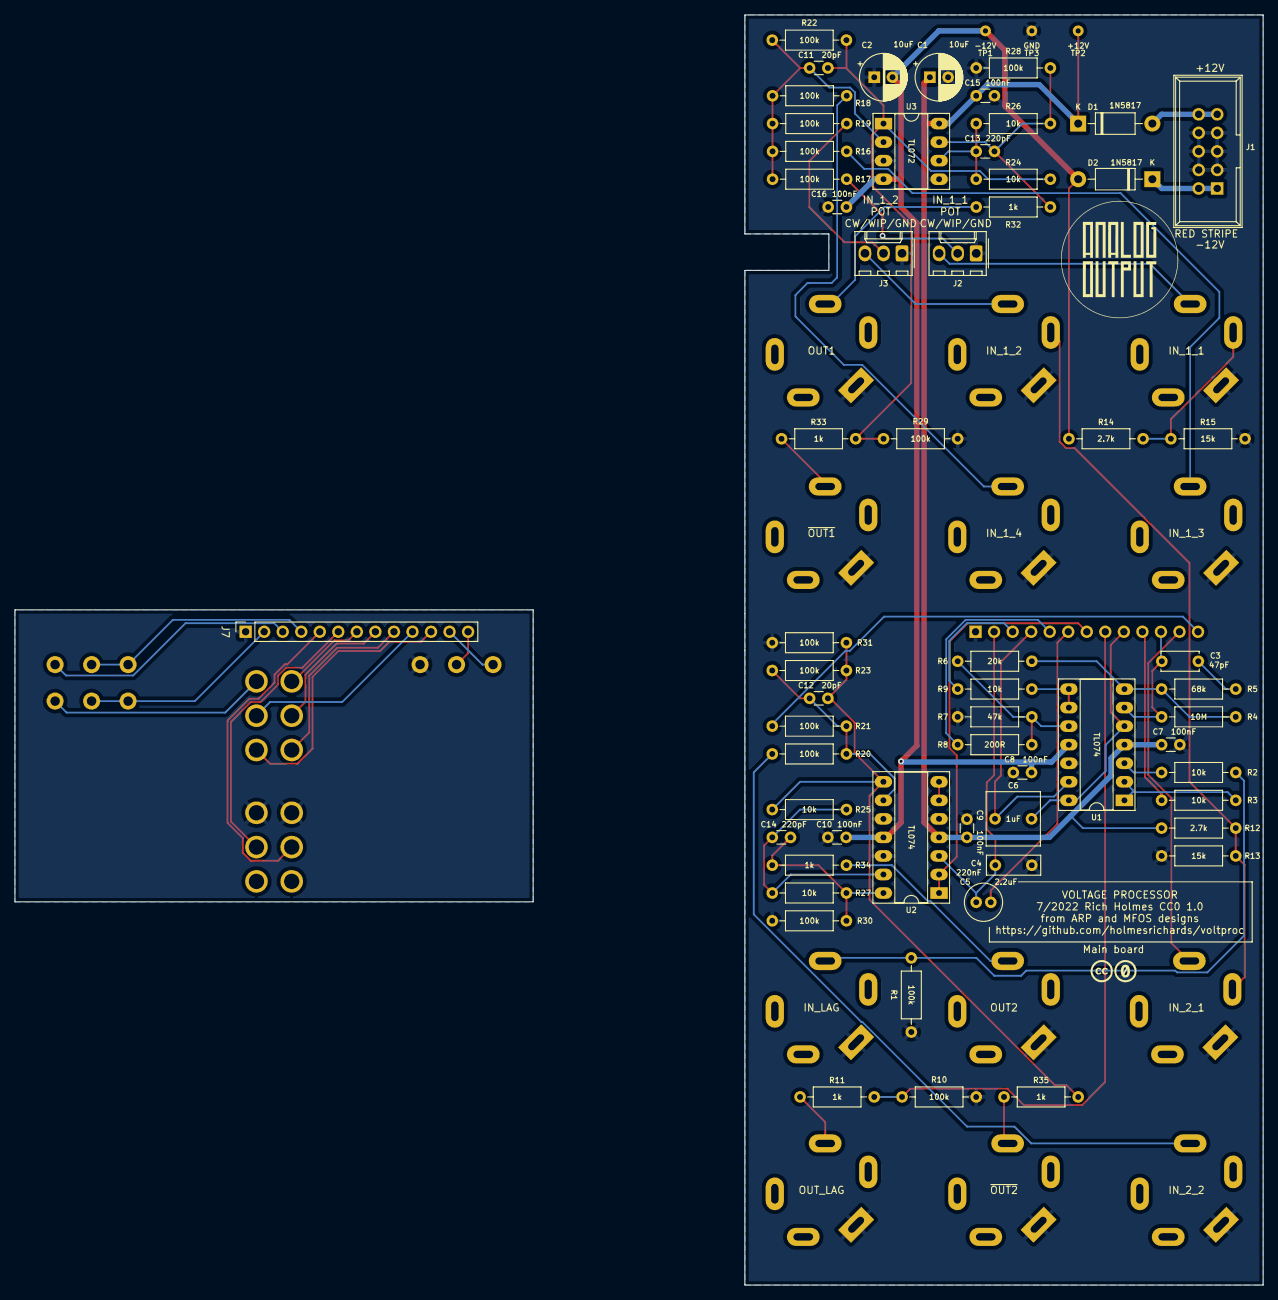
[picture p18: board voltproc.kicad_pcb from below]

Board: 2 copper layers, 71.0 x 174.0 mm, 85 parts (62 on the bottom side), 61 nets.

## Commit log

2021-11-23 Initial version
    [voltproc.kicad_pcb, voltproc.kicad_sch]
2021-11-24 normal 2nd pot on 1st section
    [voltproc.kicad_sch]
2021-11-25 Update pot symbols
    [voltproc.kicad_sch]
2021-12-05 README edit; panel art
    [voltproc.kicad_sch]
2022-02-01 Better .gitignore; add test points
    [voltproc.kicad_sch]
2022-04-03 reorg schematic, RC and linear lag
    [linrclag.kicad_sch, voltproc.kicad_pcb, voltproc.kicad_sch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]
2022-04-30 Redo layout
    [linrclag.kicad_sch, voltproc.kicad_pcb, voltproc.kicad_sch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]
2022-06-10 post breadboard revisions
    [linrclag.kicad_sch, voltproc.kicad_pcb, voltproc.kicad_sch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]
2022-07-08 Tidy up PCB
    [voltproc.kicad_pcb, voltproc.kicad_sch, voltproc_summers.kicad_sch]
2022-07-08 Panel KiCad
    [voltproc_panel.kicad_pcb, voltproc_panel.kicad_sch]
2022-08-19 CC0 add version
    [voltproc.kicad_pcb]
2022-09-23 Pre fab tweaks, Gerbers, cap descriptions
2022-11-09 Fix dual pot footprint
    [voltproc.kicad_pcb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]
2022-11-12 final pre fab tweaks
    [linrclag.kicad_sch, voltproc.kicad_pcb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]
2022-11-26 R7->47k; documentation and photos
    [linrclag.kicad_sch, voltproc.kicad_pcb, voltproc.kicad_sch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]
2022-12-02 Glare at one nonconformist jack and make it behave
    [voltproc.kicad_pcb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]

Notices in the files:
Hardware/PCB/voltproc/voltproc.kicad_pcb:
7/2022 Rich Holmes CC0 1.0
